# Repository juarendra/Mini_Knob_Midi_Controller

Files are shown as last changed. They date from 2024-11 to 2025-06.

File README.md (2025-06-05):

# Mini_Knob_Midi_Controller

## Preview Design 
<p align="center">
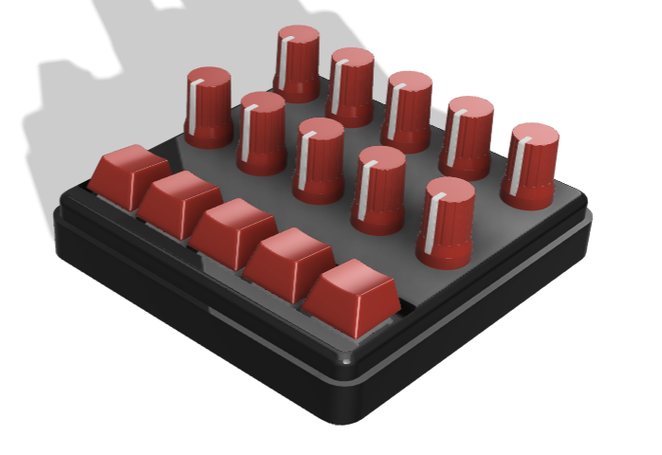
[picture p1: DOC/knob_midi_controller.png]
    
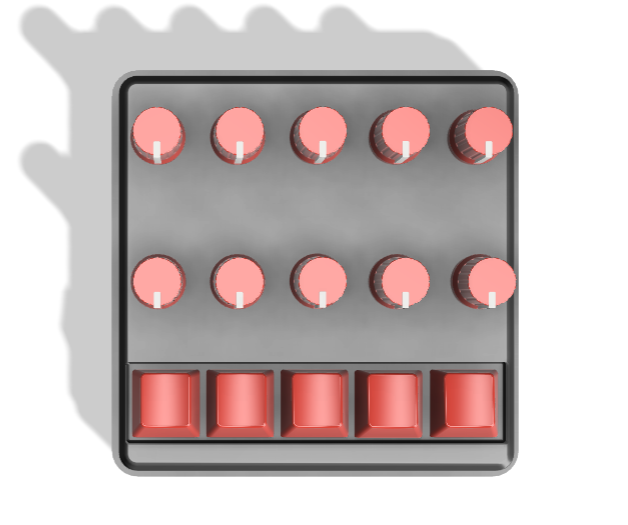
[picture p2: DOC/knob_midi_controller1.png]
    
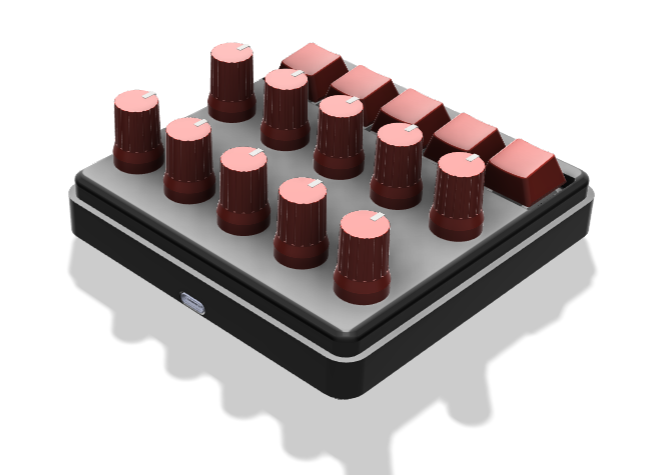
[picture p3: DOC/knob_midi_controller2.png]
    
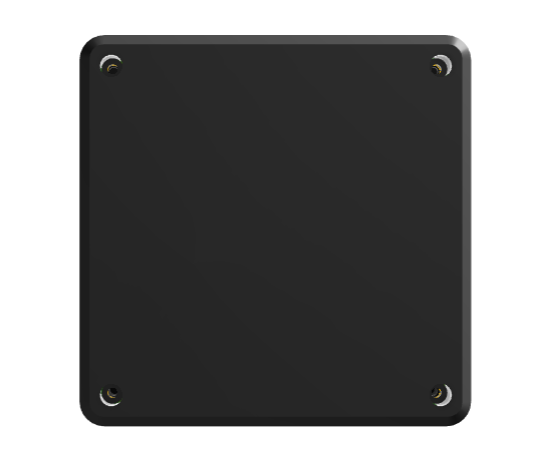
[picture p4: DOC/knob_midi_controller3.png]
    
</p>
## Preview Product 
<p align="center">
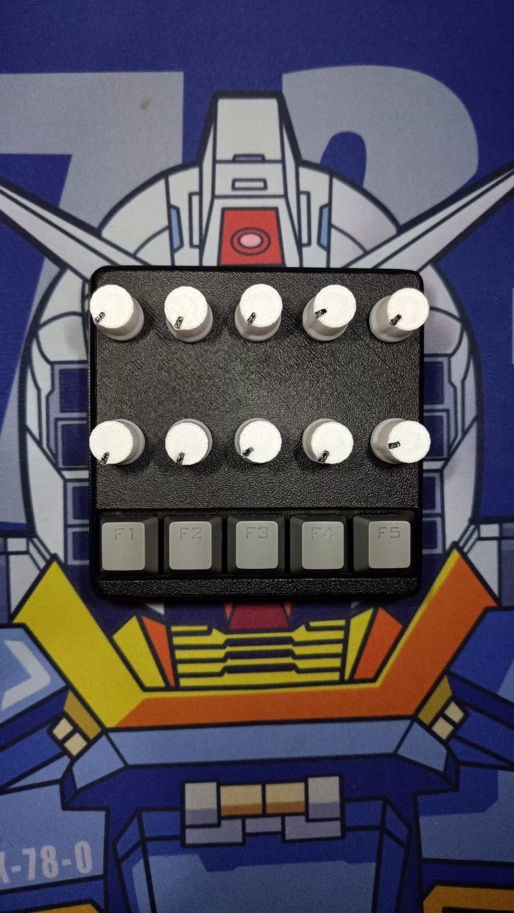
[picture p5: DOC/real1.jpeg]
    
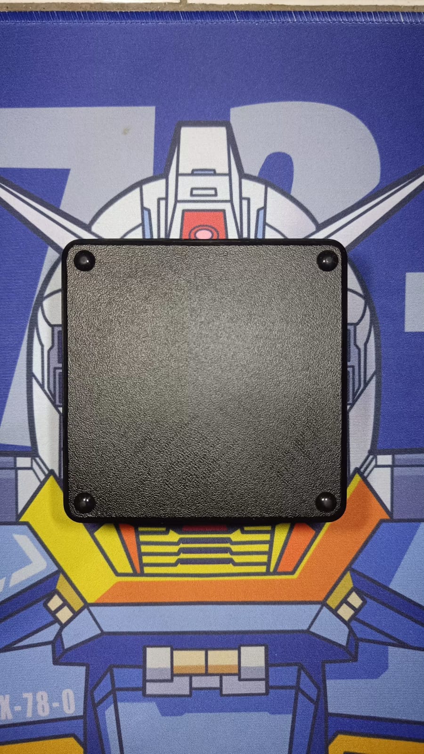
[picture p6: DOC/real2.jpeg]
    
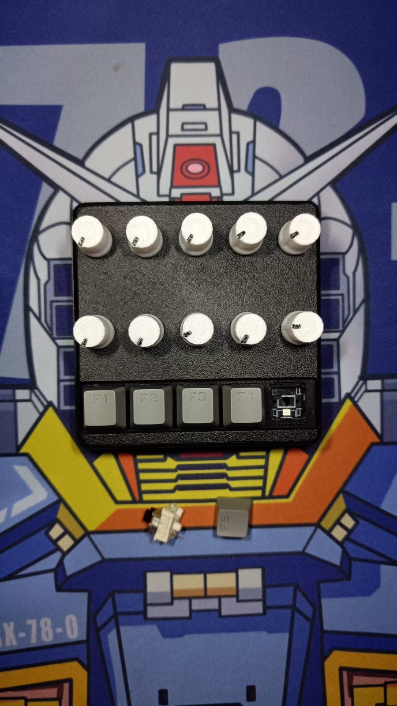
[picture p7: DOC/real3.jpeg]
    
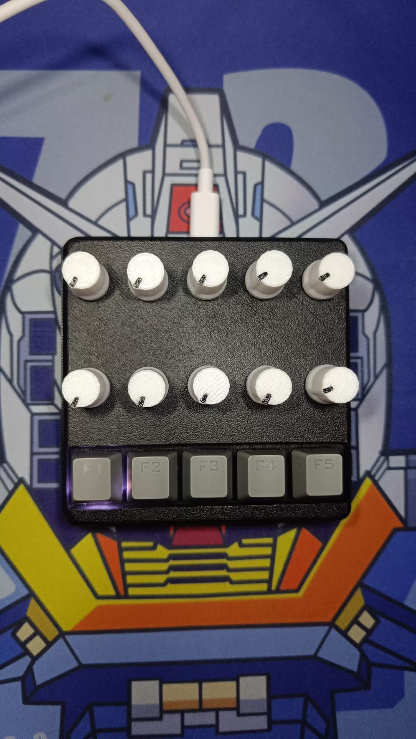
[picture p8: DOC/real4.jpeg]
    
</p>

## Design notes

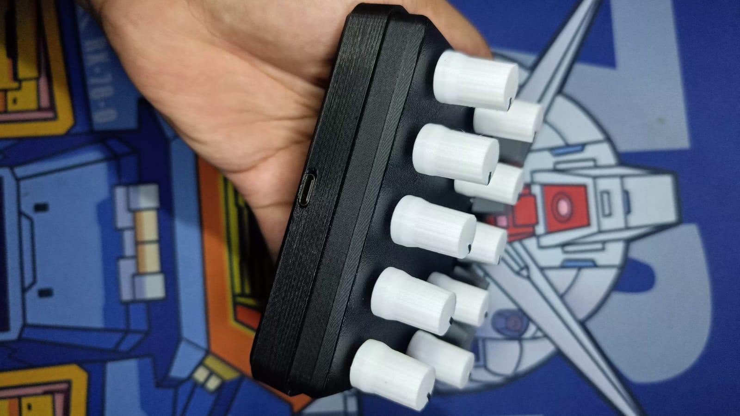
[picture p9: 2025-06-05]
DOC/real5.jpeg

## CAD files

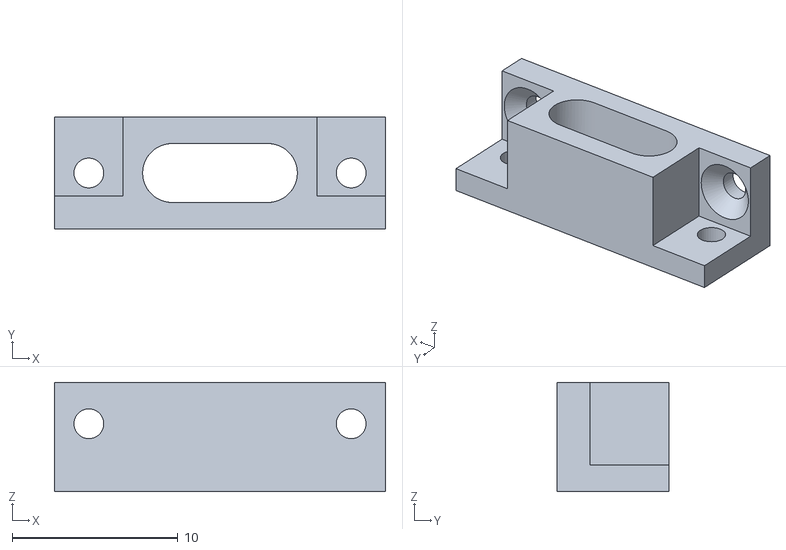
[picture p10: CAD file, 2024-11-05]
HARDWARE/CASE/USB_HOLDER.stl
20.0 x 6.75 x 6.60

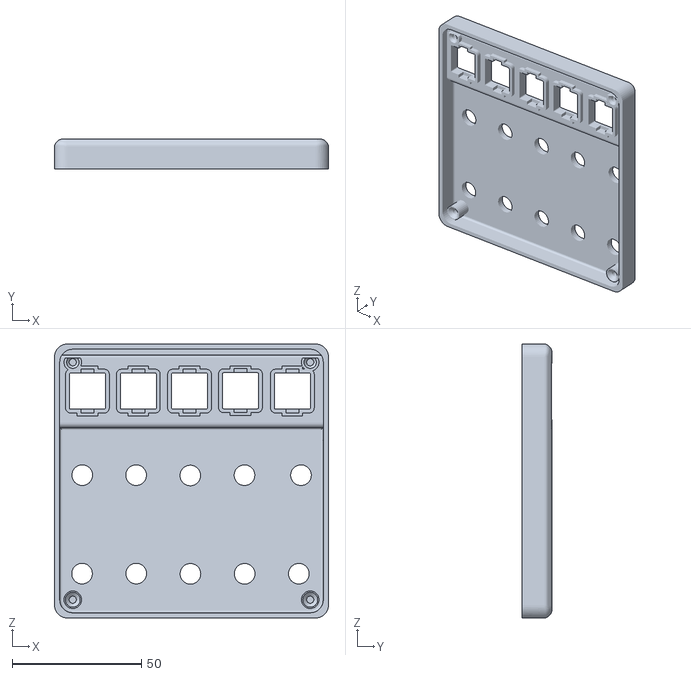
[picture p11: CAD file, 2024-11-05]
HARDWARE/CASE/TOP_KNOB_MIDI_CONTROLLER.stl
105.9 x 11.5 x 105.9

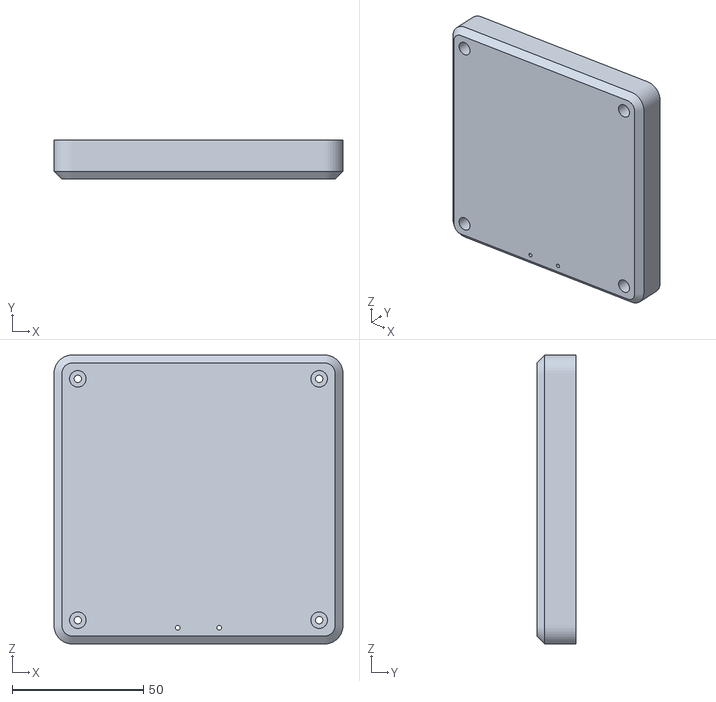
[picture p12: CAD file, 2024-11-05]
HARDWARE/CASE/BOTTOM_KNOB_MIDI_CONTROLLER.stl
109.9 x 15.0 x 109.9

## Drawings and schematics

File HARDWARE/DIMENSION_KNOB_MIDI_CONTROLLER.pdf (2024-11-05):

# 109.95 ¹⁰⁶

106.05 102

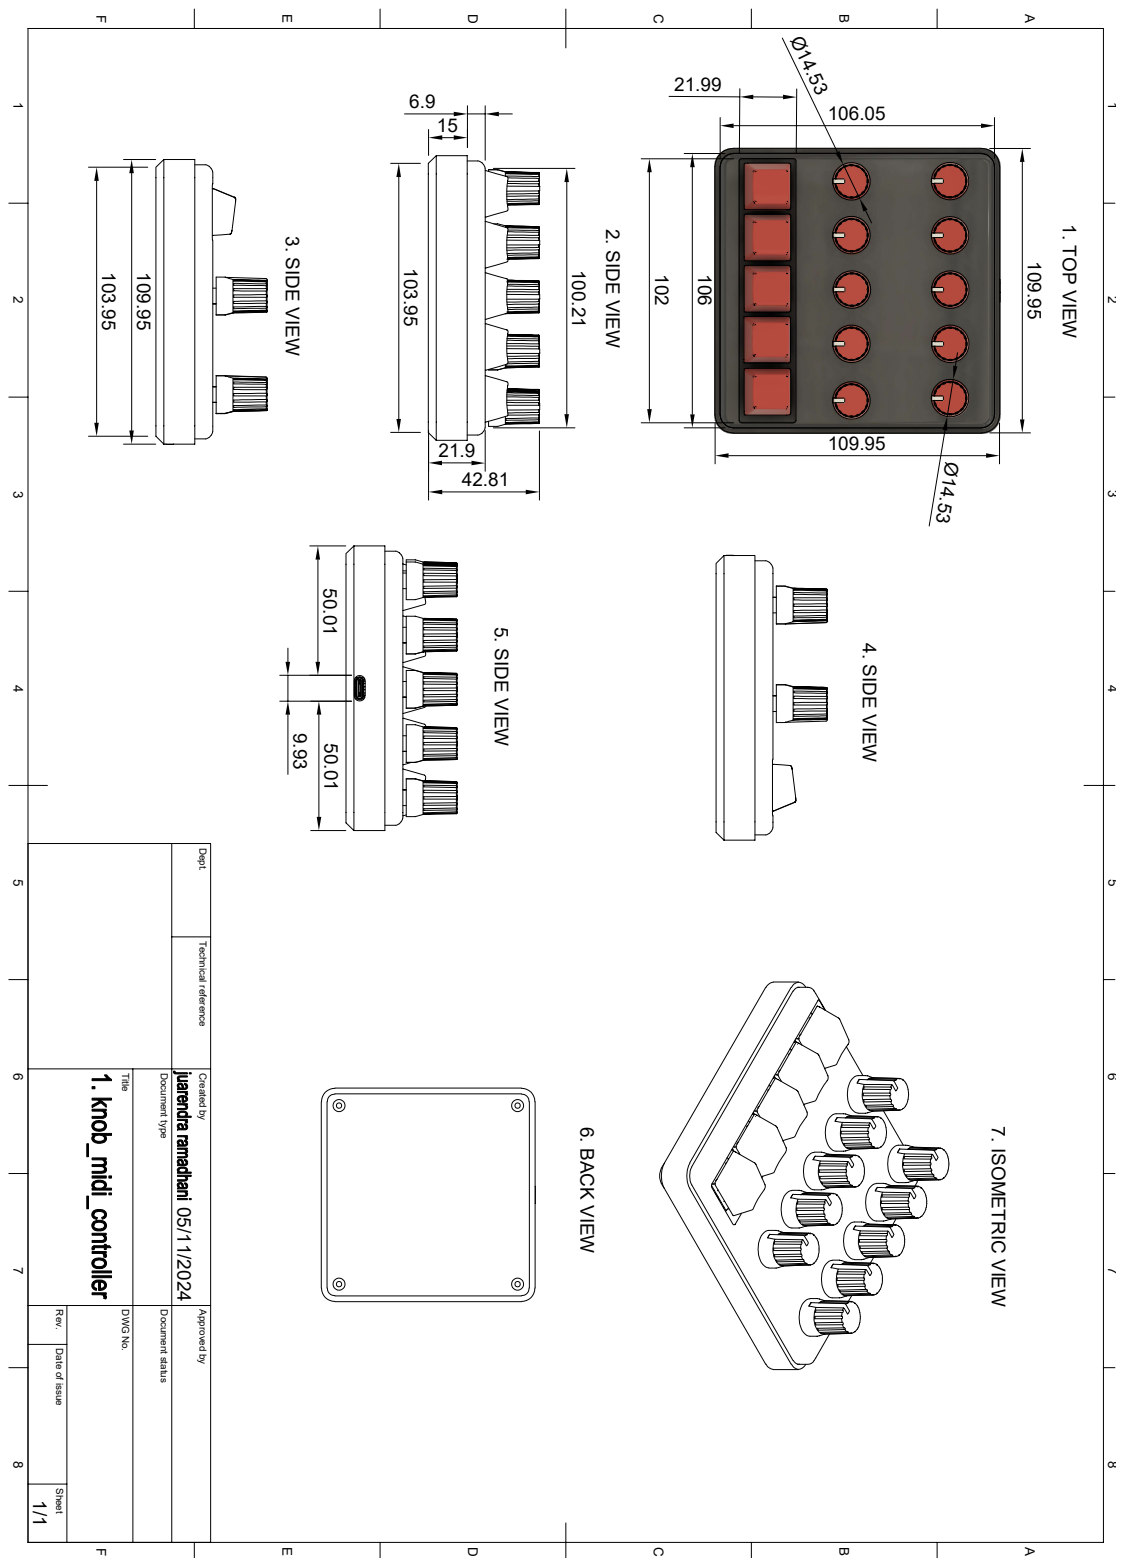
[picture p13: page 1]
21.9 ¹⁰³.95; 2. SIDE VIEW; 1. TOP VIEW ³. SIDE VIEW; 4. SIDE VIEW ⁵. SIDE VIEW; 6. BACK VIEW; 7. ISOMETRIC VIEW

1 A 2 3 4 5 6 7 8 1 2 3 4 5 6 7 8 FEDCB FEDCBA Dept. Technical reference Created by Approved by Title DWG No. Document type Document status Rev. Date of issue Sheet 05/11/2024 1/1 109.95

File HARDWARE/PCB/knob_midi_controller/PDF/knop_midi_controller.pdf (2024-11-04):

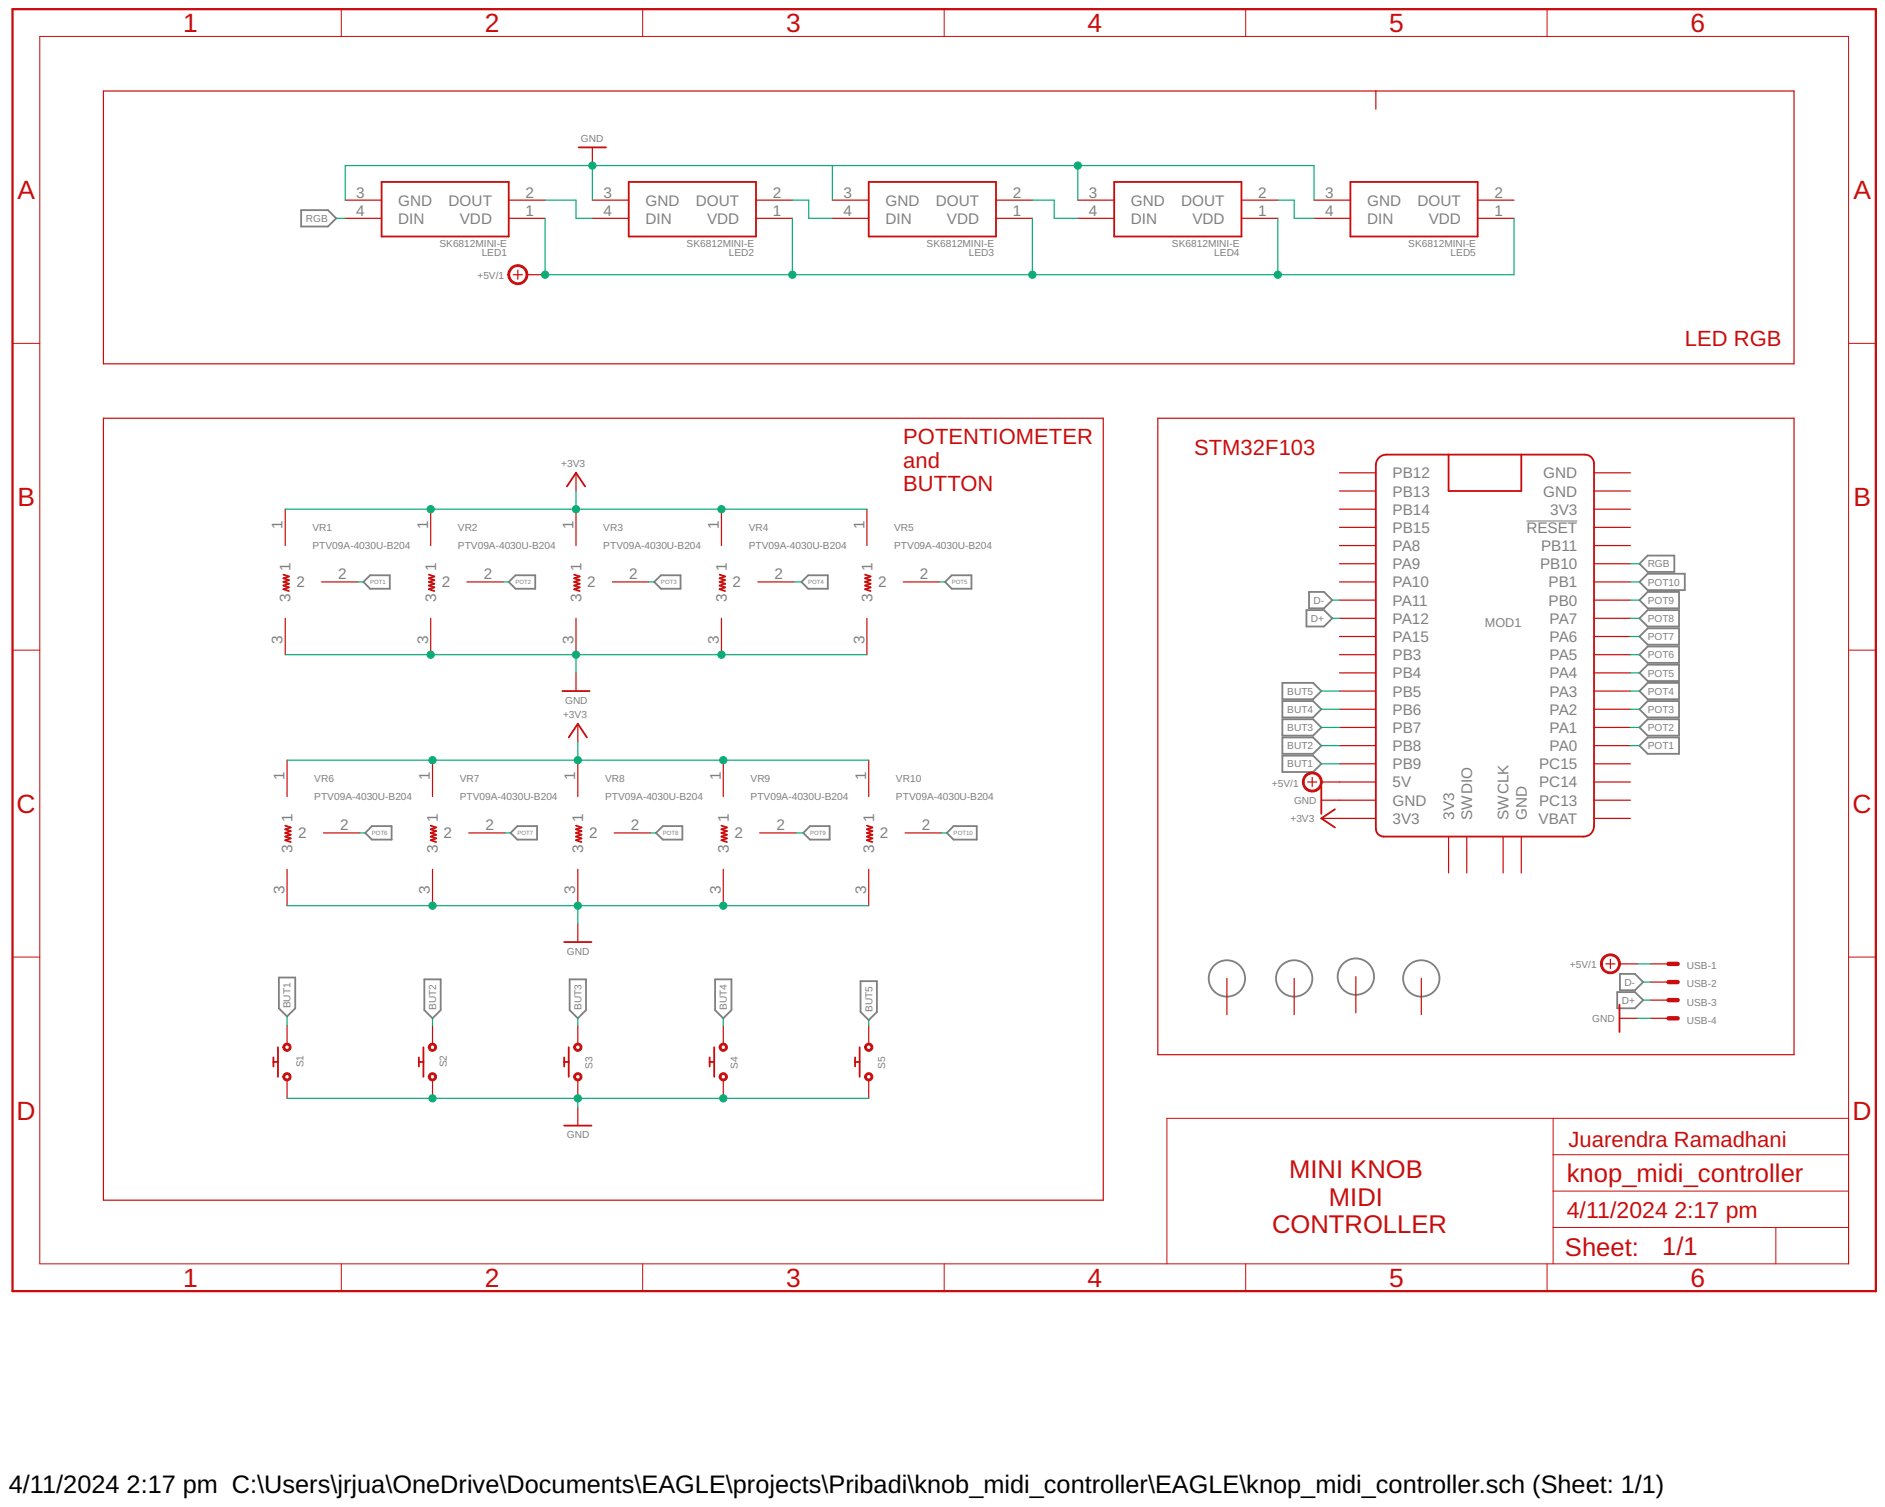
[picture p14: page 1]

USB-1 USB-2 USB-3 USB-4

4/11/2024 2:17 pm C:\Users\jrjua\OneDrive\Documents\EAGLE\projects\Pribadi\knob_midi_controller\EAGLE\knop_midi_controller.sch (Sheet: 1/1)

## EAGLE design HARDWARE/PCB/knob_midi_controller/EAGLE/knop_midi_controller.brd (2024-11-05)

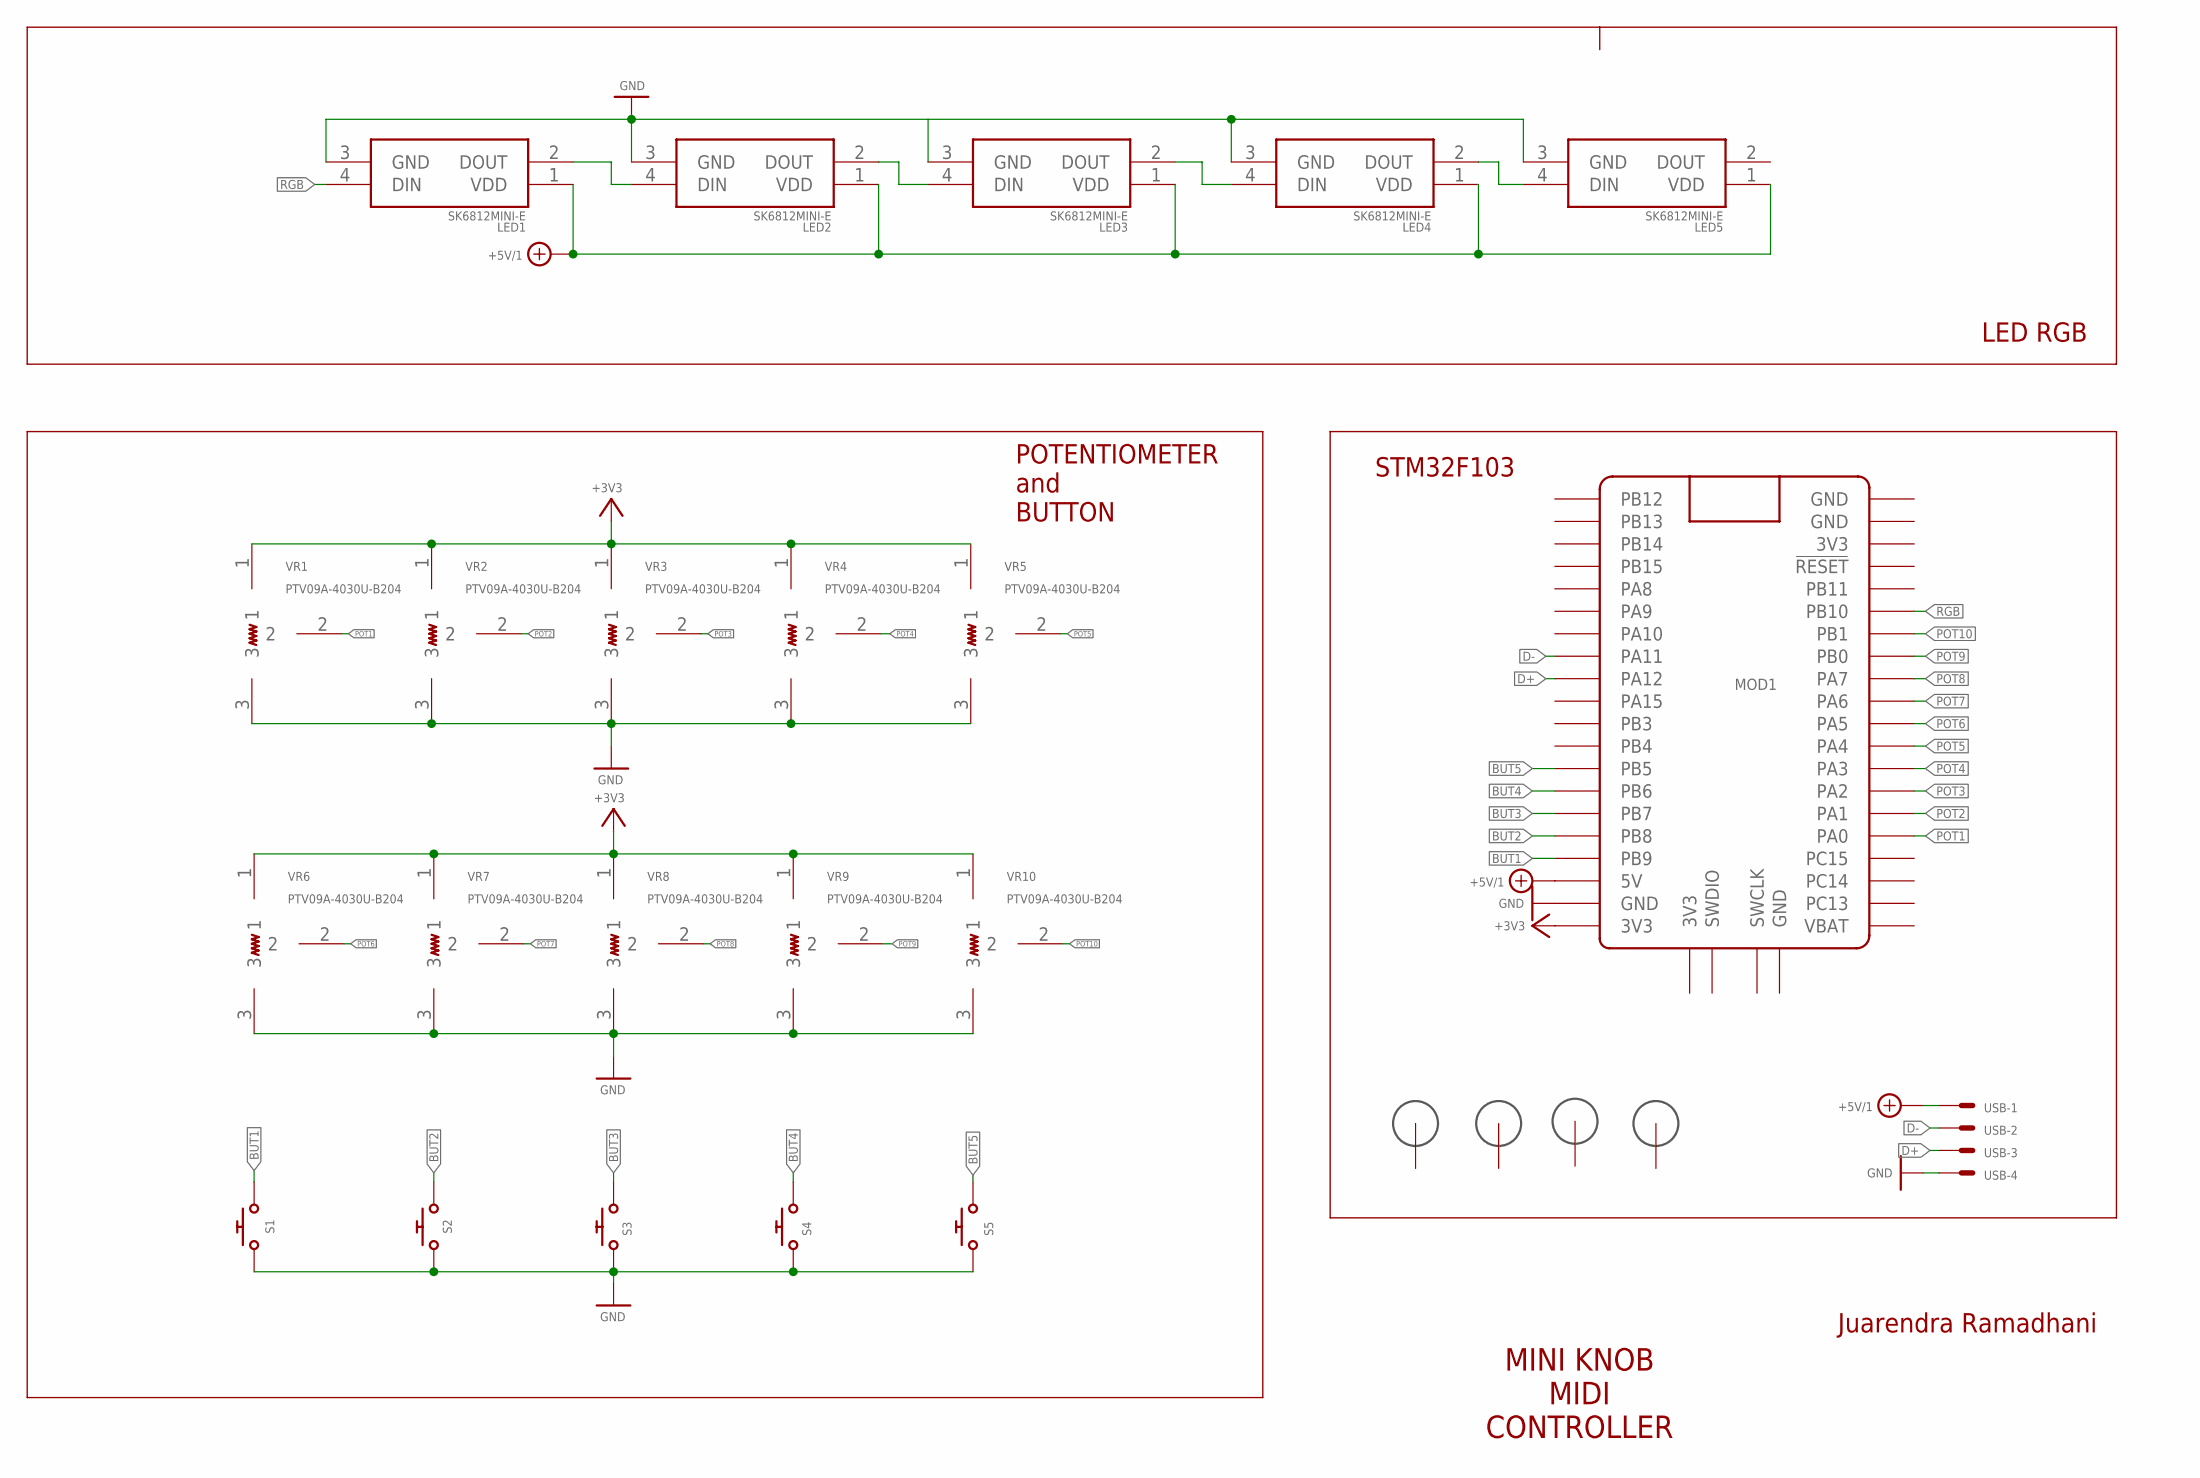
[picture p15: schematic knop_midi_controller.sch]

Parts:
H1, H2, H3, H4: 3MM_HOLE
LED1, LED2, LED3, LED4, LED5: SK6812MINI-E; SK6812MINIE
MOD1: BLUE_PILL
S1, S2, S3, S4, S5: CHERRY_MX_WITH_KEILWITH_KEIL; CHERRY_MX_WITH_KEIL
USB: 22-23-2041
VR1, VR2, VR3, VR4, VR5, VR6, VR7, VR8, VR9, VR10: PTV09A-4030U-B204; PTV09A4020FB103

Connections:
+3V3: MOD1.P$20 (3V3), VR1.1, VR2.1, VR3.1, VR4.1, VR5.1, VR6.1, VR7.1, VR8.1, VR9.1, VR10.1
+5V/1: LED1.1 (VDD), LED2.1 (VDD), LED3.1 (VDD), LED4.1 (VDD), LED5.1 (VDD), MOD1.P$18 (5V), USB.1
BUT1: MOD1.P$17 (PB9), S1.2
BUT2: MOD1.P$16 (PB8), S2.2
BUT3: MOD1.P$15 (PB7), S3.2
BUT4: MOD1.P$14 (PB6), S4.2
BUT5: MOD1.P$13 (PB5), S5.2
D+: MOD1.P$9 (PA12), USB.3
D-: MOD1.P$8 (PA11), USB.2
GND: LED1.3 (GND), LED2.3 (GND), LED3.3 (GND), LED4.3 (GND), LED5.3 (GND), MOD1.P$19 (GND), S1.1, S2.1, S3.1, S4.1, S5.1, USB.4, VR1.3, VR2.3, VR3.3, VR4.3, VR5.3, VR6.3, VR7.3, VR8.3, VR9.3, VR10.3
unnamed: LED1.2 (DOUT), LED2.4 (DIN)
unnamed: LED2.2 (DOUT), LED3.4 (DIN)
unnamed: LED3.2 (DOUT), LED4.4 (DIN)
unnamed: LED4.2 (DOUT), LED5.4 (DIN)
POT1: MOD1.P$36 (PA0), VR1.2
POT2: MOD1.P$35 (PA1), VR2.2
POT3: MOD1.P$34 (PA2), VR3.2
POT4: MOD1.P$33 (PA3), VR4.2
POT5: MOD1.P$32 (PA4), VR5.2
POT6: MOD1.P$31 (PA5), VR6.2
POT7: MOD1.P$30 (PA6), VR7.2
POT8: MOD1.P$29 (PA7), VR8.2
POT9: MOD1.P$28 (PB0), VR9.2
POT10: MOD1.P$27 (PB1), VR10.2
RGB: LED1.4 (DIN), MOD1.P$26 (PB10)

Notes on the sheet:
LED RGB
POTENTIOMETER and BUTTON
STM32F103
MINI KNOB MIDI CONTROLLER
Juarendra Ramadhani

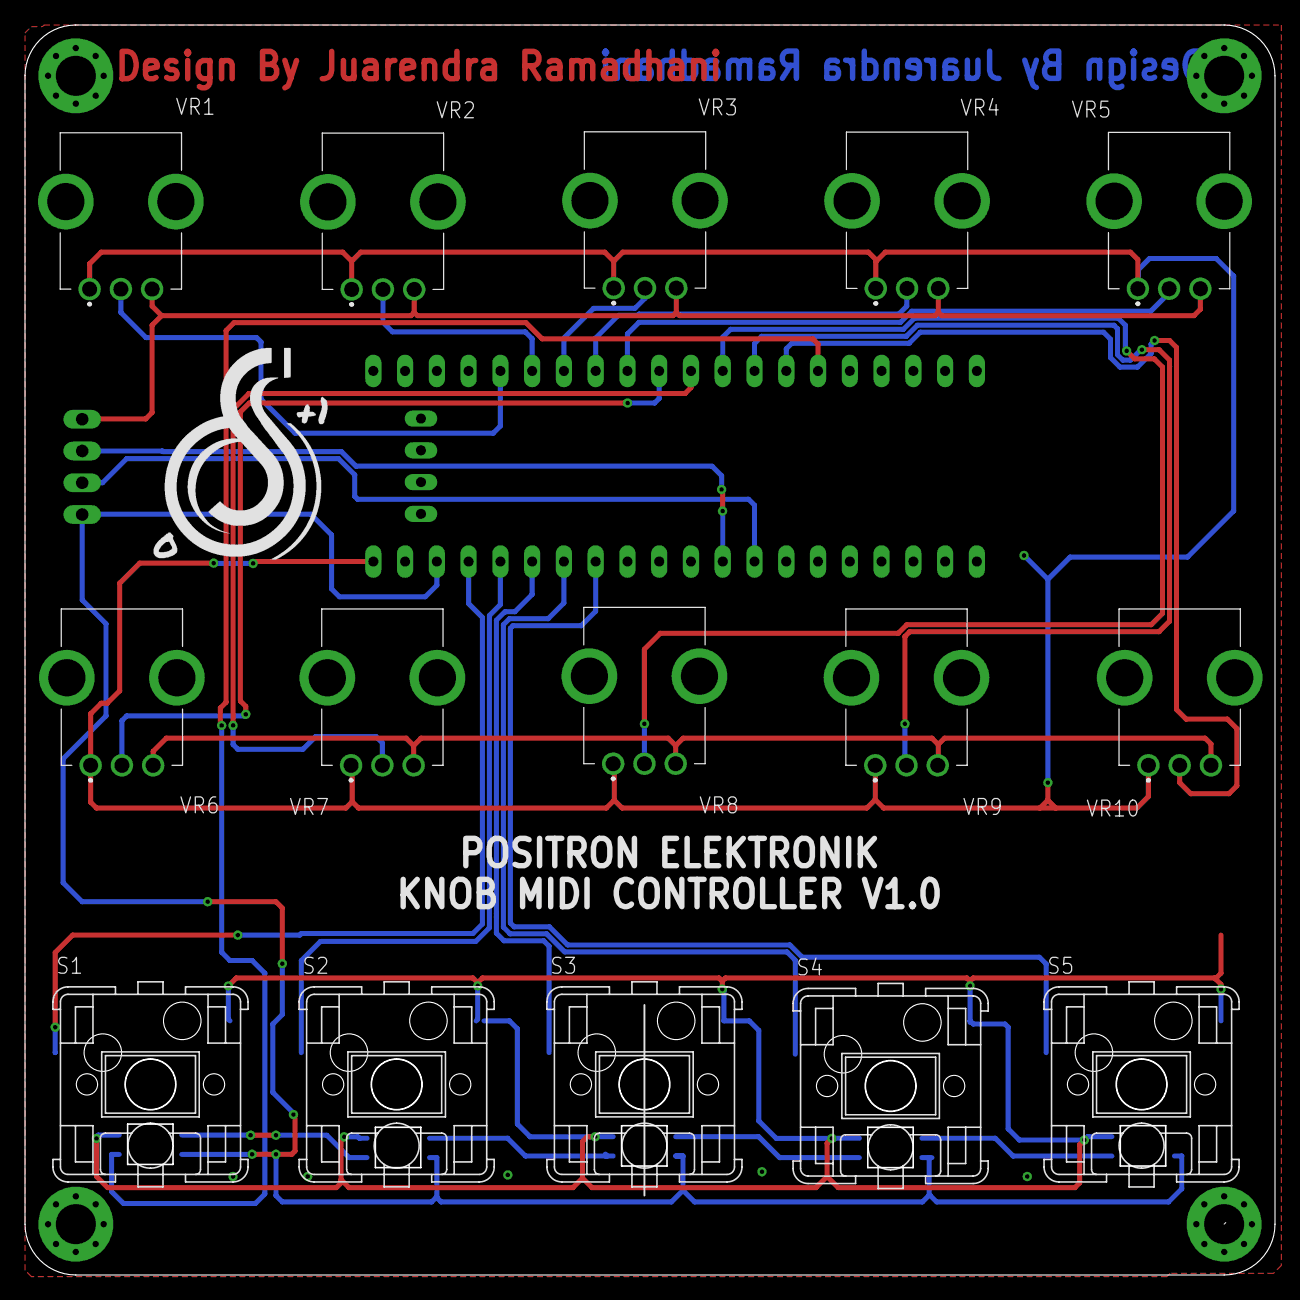
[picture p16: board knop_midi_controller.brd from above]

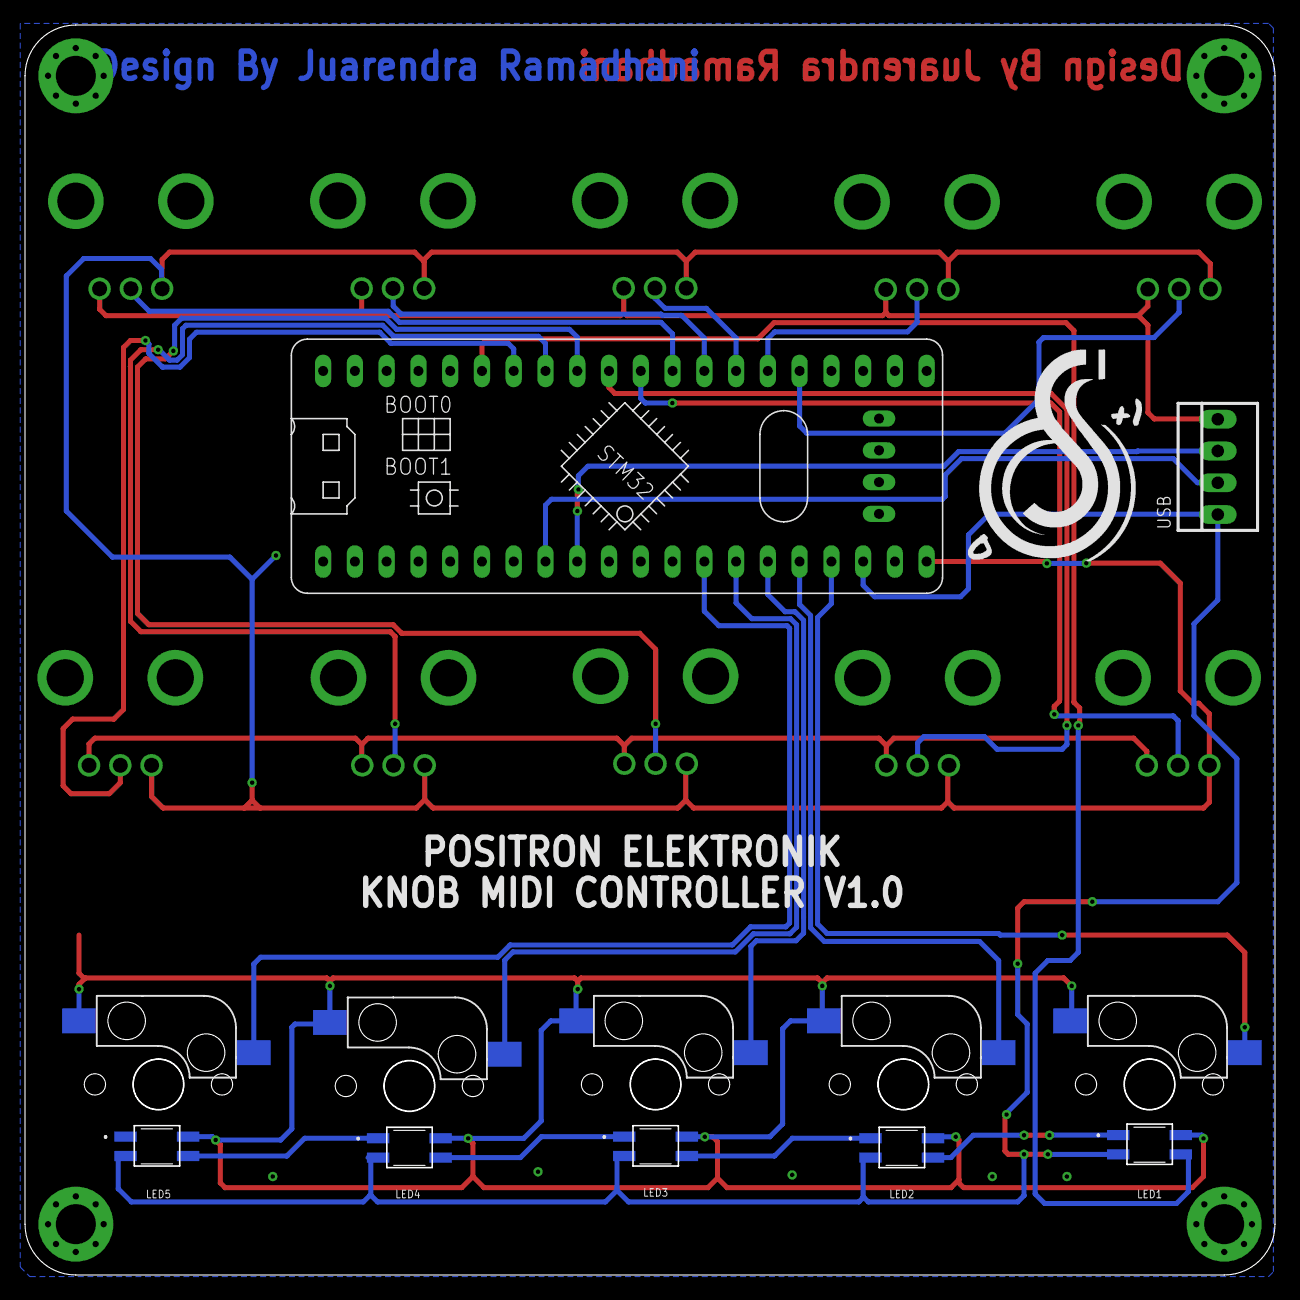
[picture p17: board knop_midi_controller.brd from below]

Board: 2 copper layers, 99.9 x 99.9 mm, 26 parts (8 on the bottom side), 25 nets.

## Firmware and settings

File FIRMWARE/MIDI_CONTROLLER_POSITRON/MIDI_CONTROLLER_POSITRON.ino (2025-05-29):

#include <USBComposite.h>
USBMIDI midi;
//#include <ResponsiveAnalogRead.h> 
#include <FastLED.h>

#define LED_PIN     PB10        // Choose a tested pin
#define NUM_LEDS    5
#define BRIGHTNESS  100
#define LED_TYPE    WS2812B
#define COLOR_ORDER GRB

CRGB leds[NUM_LEDS];

const int NUM_POT = 10;
const int NUM_BUT = 5;
const int analogInputs[NUM_POT] = {PA0, PA1, PA2, PA3, PA4, PA5, PA6, PA7, PB0, PB1};
const int digitalInput[NUM_BUT] = {PB9, PB8, PB7, PB6, PB5};
int analogSliderValues[NUM_POT];
//ResponsiveAnalogRead responsivePot[NUM_POT] = {}; 
int potCState[NUM_POT] = { 0 };  // Current state of the pot
int potPState[NUM_POT] = { 0 };  // Previous state of the pot
int potVar = 0;                 // Difference between the current and previous state of the pot

int midiCState[NUM_POT] = { 0 };  // Current state of the midi value
int midiPState[NUM_POT] = { 0 };  // Previous state of the midi value
int reading_pot = 0;

const int TIMEOUT = 300;              // Amount of time the potentiometer will be read after it exceeds the varThreshold
const int varThreshold = 20;          // Threshold for the potentiometer signal variation
boolean potMoving = true;             // If the potentiometer is moving
unsigned long PTime[NUM_POT] = { 0 };  // Previously stored time
unsigned long timer[NUM_POT] = { 0 };  // Stores the time that has elapsed since the timer was reset

int potMin = 0;
int potMax = 3070;

bool debug_pot = false;
byte midiCh = 0;
byte cc = 1;   
byte NUM_BANK = 0;

const int NUM_SAMPLES = 10;

void setup() {
  FastLED.addLeds<LED_TYPE, LED_PIN, COLOR_ORDER>(leds, NUM_LEDS);
  FastLED.setBrightness(BRIGHTNESS);

  for (int i = 0; i < NUM_POT; i++) {
    pinMode(analogInputs[i], INPUT);
  }
  for (int i = 0; i < NUM_BUT; i++) {
    pinMode(digitalInput[i], INPUT_PULLUP);
  }
  if (debug_pot){
    Serial.begin(9600);
  }
  else{
    USBComposite.setProductId(0x0031);
    midi.begin();
    while (!USBComposite);
  }
}

void loop() {
  // Light up LEDs based on active bank
  for(int i = 0; i < NUM_LEDS; i++) {
    if (i == NUM_BANK) {
      leds[i] = CRGB::White;   // Active bank LED to white
    } else {
      leds[i] = CRGB::Black;   // Others off
    }
  }
  FastLED.show();

  for (int i = 0; i < NUM_BUT; i++){
    if (!digitalRead(digitalInput[i])){
      NUM_BANK = i;
    }

  }
  if(debug_pot){
    updateSliderValues();
    printSliderValues();
    delay(100);
  }
  else {
    sendMidiValue();
    delay(10);
  }
}

void sendMidiValue() {
  int potMin = 10;    
  int potMax = 3070;

  for (int i = 0; i < NUM_POT; i++) {
    int total = 0;

    // Take multiple samples to average
    for (int s = 0; s < NUM_SAMPLES; s++) {
      total += analogRead(analogInputs[i]);
      delayMicroseconds(100); // Small delay between reads
    }

    reading_pot = total / NUM_SAMPLES; // Calculate average reading
    potCState[i] = reading_pot;

    // Map and constrain stable average value
    midiCState[i] = map(potCState[i], potMin, potMax, 127, 0);
    midiCState[i] = constrain(midiCState[i], 0, 127);

    // Dead zones to further stabilize extremes
    if (midiCState[i] <= 1) midiCState[i] = 0;
    if (midiCState[i] >= 126) midiCState[i] = 127;

    potVar = abs(potCState[i] - potPState[i]);
    if (potVar > varThreshold) {
      PTime[i] = millis();
    }
    timer[i] = millis() - PTime[i];

    potMoving = timer[i] < TIMEOUT;

    // Only send MIDI if there is meaningful change
    if (abs(midiCState[i] - midiPState[i]) > 1) {
      midi.sendControlChange(midiCh, cc + i + (NUM_BANK * 10), midiCState[i]);
      potPState[i] = potCState[i];
      midiPState[i] = midiCState[i];
    }
  }
}

void updateSliderValues() {
  for (int i = 0; i < NUM_POT; i++) {
     analogSliderValues[i] = analogRead(analogInputs[i]);
  }
}

void printSliderValues() {
  for (int i = 0; i < NUM_POT; i++) {
    String printedString = String("Slider #") + String(i + 1) + String(": ") + String(analogSliderValues[i]) + String(" mV");
    Serial.write(printedString.c_str());

    if (i < NUM_POT - 1) {
      Serial.write(" | ");
    } else {
      Serial.write("\n");
    }
  }
}

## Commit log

2024-11-04 FEAT: add pcb
    [knop_midi_controller.brd, knop_midi_controller.sch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]
2024-11-05 FEAT: add 3d desain case, model and dimension
    [BOTTOM_KNOB_MIDI_CONTROLLER.stl, TOP_KNOB_MIDI_CONTROLLER.stl, USB_HOLDER.stl]
2024-11-05 FEAT: fix problem placement pcb and add name and logo
    [knop_midi_controller.brd]
2024-11-06 FEAT: update gerber
    [copper_bottom.gbr, copper_top.gbr, drill_1_16.xln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]
2025-05-28 FEAT: add init led rgb
2025-05-29 FEAT: add sample reading pot
2025-06-05 FEAT: add library led rgb controller
